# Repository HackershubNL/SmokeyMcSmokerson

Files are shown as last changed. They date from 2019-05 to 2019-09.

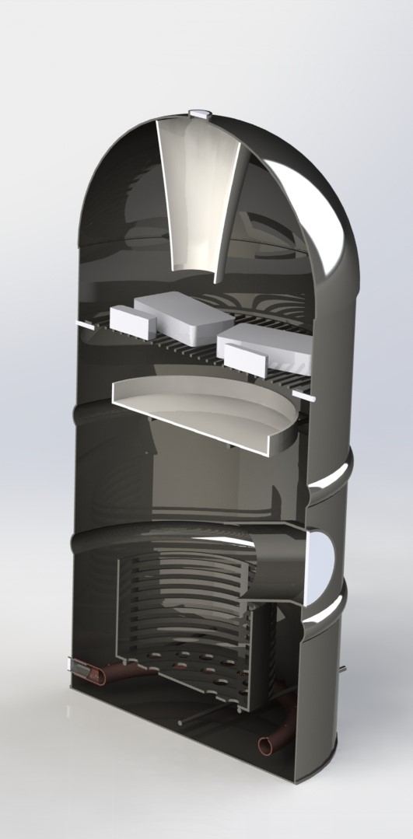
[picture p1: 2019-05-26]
Images/Full Assembly Rendering.JPG

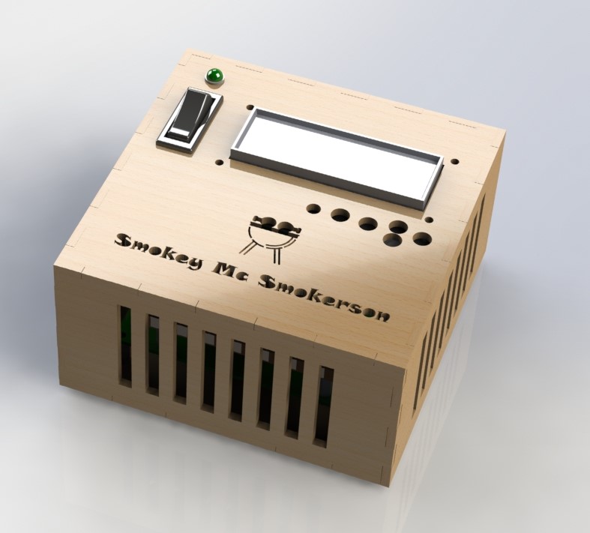
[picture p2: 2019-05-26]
Images/Controller Rendering.JPG

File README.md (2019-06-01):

# SmokeyMcSmokerson

## Introduction

This was inspired by the following projects:  
https://github.com/willblev/SmokeyTheBarrel  
https://github.com/jerrychangusa/ES96-Smart-Smoker  

Other sites and pages that were used in the process of making this project:  
https://amazingribs.com/  
https://genuineideas.com/ArticlesIndex/thecrutch.html

## Getting Started

The controller can be used separate from this smoker, meaning that you can use it on your own project. You will only need to place 4 of the 5 thermocouples in your smoker around the grill and have the fan blow into the bottom.

### Building the thing

It is currently in the last stages of design, as soon as the building starts, the build log will be published on: https://hackaday.io/project/165762-smokey-mc-smokerson  

### Running the thing

See Software/Controller for more info.

## Structure

```
-- Hardware  
  |-- Electronics - Design for the controller hardware  
  |-- Smoker - Design for the smoker itself  

-- Software  
  |-- Controller - Controller software

-- Images - Bunch of images
```

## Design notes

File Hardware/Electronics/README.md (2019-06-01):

# Smokey Mc Smokerson - Controller Hardware

## Intro

This is revision number one, already some improvement points have been identified such as using standard fan connectors instead of screw terminals and additional smoothing capacitors need to be included.  
1/6/2019 - Latest .sch and .brd files have 4 pin fan headers instead of the screw terminals.

## Design Decisions

The SN74AHCT125N Buffer is added to level shift the PWM signal from 3.3v to 5v. This has been done for better compatibility with different fans. Certain ones seem to accept 3.3v PWM signal but most 12V fans seem to require a 5v signal.

Plans for the controller housing can be found in Hardware/Smoker.

Additional GPIO pins are available through the 6 pin header for future usage.

The fan which will be used is the Sanyo Denki 9GA0412P6G001*, this is chosen due to the high static pressure because it will need to blow through a hose and the airflow spreader.  
*https://nl.farnell.com/sanyo-denki/9ga0412p6g001/axial-fan-40mm-12vdc-14-8cfm-47dba/dp/2768815 

## Bill of Materials  

Farnell shopping cart csv is included but the following items are not on the list:  
- Raspberry Pi + SD card (Assuming you have one)
- Thermocouple boards and probes, see link to Aliexpress below
- Fans

And some items have a minimum order quantity so you will get more than required.

### Main board

- 5x 5-pin female headers
- 2x 3-pin screw terminals - In latest .sch and .brd files these are switched for 4 pin headers so you can use a PC fan without having to cut the wire. The fan I chose comes with leaded connectors.
- 1x 6-pin male header
- 1x 4-pin male header
- 1x 2-pin male header
- 1x 2-pin Molex Mini Fit Jr Header
- 1x 5.5mm Barrel Jack 
- 1x 14-pin DIP socket
- 1x 40-pin female GPIO header  
- 1x RECOM R-78B5.0-2.0 5V 2A DC/DC Converter - You can use alternatives to this such as the V7805-2000 or any other TO220 Switching Regulators. Opted for the 2A version due to minimal price difference and it's nice to have an overhead.
- 1x 10uF capacitor  
- 1x 22uF capacitor  
- 1x 220 ohm resistor  
- 1x SN74AHCT125N

### Raspberry Pi

- 1x Raspberry Pi Zero W  
- 1x 40-pin male GPIO header

### Control Panel

- 1x Adafruit LCD display with I2C board
- 1x Panel mount led indicator
- 1x Rocker Switch 
- 1x 2 pin Molex Mini Fit Jr Receptacle  
- 2x Molex Crimp Contacts  
- 2x female jumper wire soldered to led indicator  
- 4x female - female jumper wires for display to main board
- 8x 11mm M2.5 standoffs
- 8x M2.5 - 6mm screws
- 8x M2.5 nuts

### Sensors

- 5x MAX6675 Thermocouple boards with probe - https://nl.aliexpress.com/item/MAX6675-Module-K-Type-Thermocouple-Thermocouple-Senso-Temperature-Degrees-Module-for-arduino/32841448771.html

### Other

- 1 or 2 12V PWM fans (according to barbecue forums a single 10CFM fan should be sufficient)

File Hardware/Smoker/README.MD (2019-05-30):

# Smokey Mc Smokerson - Smoker Design

## Introduction

After going through many options such as using flower pots, the decision was made to base it on an oil drum.  
The drum does not have as good flow and heat retention charactertics as flower pots or custom making a ceramic thing but it is fairly cheap and large.  
Most components have been modeled after off the shelf items available from hardware, garden and house supply stores.  
The only custom made items are the controller housing and fan mount (laser cut wood) and fan nozzle (3D printed), these will be placed in the `Custom Design Files` folder.

## Structure

The main assembly is `Barrel Smoker Assembly.SLDASM` which consists of multiple single parts and sub assemblies.

## Bill of Materials

- Online?
  - 55 Gallon (200 liter) Oil Drum
- Hardware Store
  - 55 cm barbecue grill
  - Expanded metal sheet (to make the coal basket) - 1x 35cm circle and 1x 110cm x 20cm
  - Steel wire to weave the metal sheets into a basket
  - 5x M10 1m threaded rod
  - 4x M10 50mm bolts
  - Bunch of M10 nuts
  - Bunch of M10 washers
  - 8x M6 washers - To attach the thermocouples, depending on which ones you get you might need another size
  - 4x M6 nuts - To attach the thermocouples, depending on which ones you get you might need another size
- Dollar Store style place
  - Largest round oven dish - preferably around 40cm diameter

## Building the thing

Coming soon

## Notes

Creating the air diffuser can be an expensive item due to the pipe size, alternatively use a 1 1/4 inch skin fitting. This is a fitting meant for ship through hull fluid flow.

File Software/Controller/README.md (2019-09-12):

# Smokey Mc Smokerson - Controller Software

## Introduction

Currently work in progress, this is conceptual code right now as the hardware has not been delivered yet. Simulated mode is built-in to show the usage.

## Running the thing

For full info check the wiki.

### Setup

Install dependencies with:  
`sudo bash ./setup.sh`

In `config.json` set your API key and optionally your Blynk server address. If the server address is an empty string, it will use the public Blynk Servers.

### Usage

Run the hardware tests with:  
`python3 ./smokey_mc_smokerson/run_tests.py`  
This will test the thermocouples and fan(s).

When using the setup script, it will install the controller as a service which starts on boot.  
To start and stop the service you can use:  
```
sudo /etc/init.d/smokey_service start
and
sudo /etc/init.d/smokey_service stop
```

Alternatively you can run it separately:  
`python3 ./smokey_mc_smokerson/smokey_mc_smokerson.py`  

The startup temperature values are located in `globals.py`, these can be changed using the Blynk app later on.

If it is run on anything but a Raspberry Pi, it will go into a simulated mode.

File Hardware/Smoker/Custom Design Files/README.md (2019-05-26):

# Smokey Mc Smokerson - Smoker Design - Custom Design Files

Production ready designs for custom made items are here / will go here:

- Controller Housing
- Fan Mount
- Fan Nozzle
  - Fan Nozzle.STL

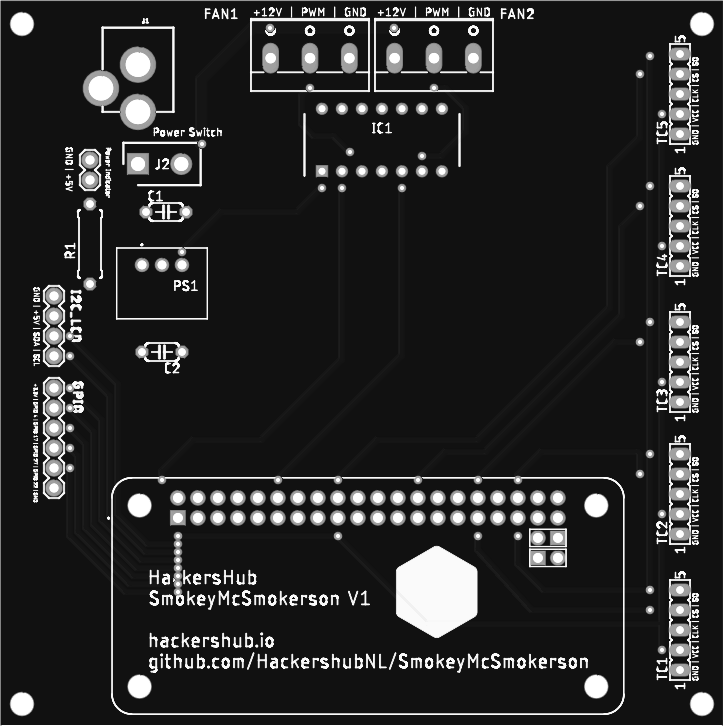
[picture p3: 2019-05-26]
Images/Controller Board Top View.png

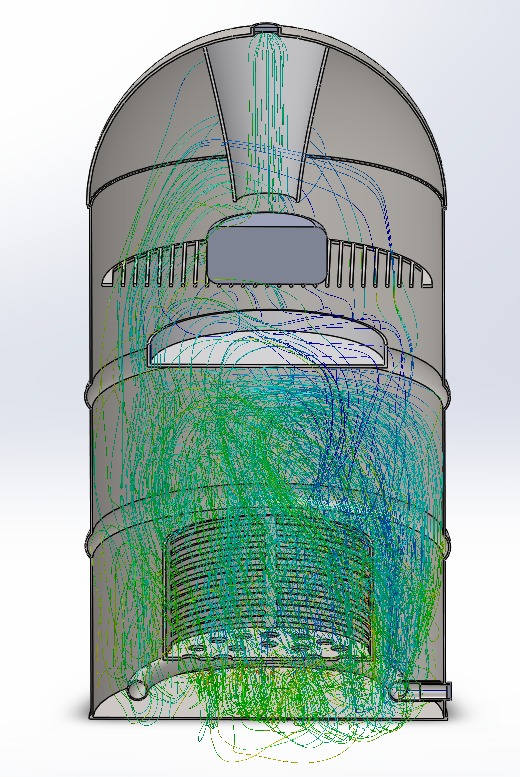
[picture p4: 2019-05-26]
Images/Air Flow Analysis.jpeg

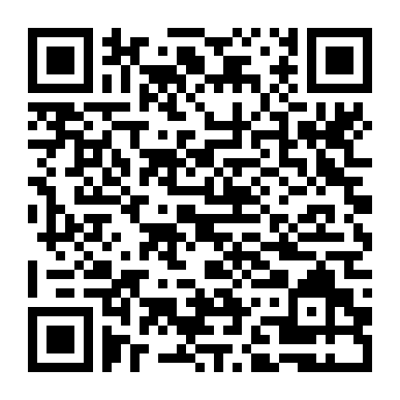
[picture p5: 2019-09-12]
Software/Controller/blynk_app.png

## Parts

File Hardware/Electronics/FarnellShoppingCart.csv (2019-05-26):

Artikelnr. | Ordercode | RoHS-compatibel? | Uw art.nr. | Opmerkingen | Hoeveelheid | Artikelnummer fabrikant | Naam fabrikant | Fabrikant / beschrijving | Beschikbaarheid | Prijs per stuk | Artikelprijs | Prijs na korting
1 | 1578490 | RoHS: YES / FTALATEN: TBA |  |  | 5.0 | MC34657 | MULTICOMP | MULTICOMP Wire-To-Board Connector, 4.2 mm, 2 Contacts, Header, 2266(5566)S Series, Through Hole, 2 Rows | 689 | 0.2650 | 1.33
2 | 1704304 | RoHS: YES / FTALATEN: TBA |  |  | 10.0 | 39-01-3022 | MOLEX | MOLEX Connector Housing, No Pull Tabs, UL 94V-2, Mini-Fit Jr. 5557 Series, Receptacle, 2 Ways, 4.2 mm | 17212 | 0.2120 | 2.12
3 | 1717002 | RoHS: YES / FTALATEN: TBA |  |  | 10.0 | CTB5202/3 | CAMDENBOSS | CAMDENBOSS Standard Terminal Block, Wire to Board, CTB5202 Series, 3 Contacts, 5 mm, Terminal Block, PCB | 11530 | 0.3640 | 3.64
4 | 1593461 | RoHS: YES / FTALATEN: TBA |  |  | 10.0 | 2212S-05SG-85 | MULTICOMP | MULTICOMP Board-To-Board Connector, 2.54 mm, 5 Contacts, Receptacle, 2212S Series, Through Hole, 1 Rows | Out of Stock | 0.1460 | 1.46
5 | 1854512 | RoHS: YES / FTALATEN: TBA |  |  | 1.0 | FC681465P | CLIFF ELECTRONIC COMPONENTS | CLIFF ELECTRONIC COMPONENTS DC Power Connector, Socket, 5 A, 2.5 mm, PCB Mount, Solder | 15554 | 1.7300 | 1.73
6 | 2668404 | RoHS: YES / FTALATEN: TBA |  |  | 10.0 | DILB14P-223TLF | AMPHENOL ICC (FCI) | AMPHENOL ICC (FCI) IC & Component Socket, 14 Contacts, DIP Socket, 2.54 mm, 7.62 mm, Copper Alloy | 3447 | 0.1480 | 1.48
7 | 2847248 | RoHS: YES / FTALATEN: TBA |  |  | 1.0 | 2214S-40SG-85 | MULTICOMP | MULTICOMP Board-To-Board Connector, 2.54 mm, 40 Contacts, Receptacle, Through Hole, 2 Rows | 5824 | 1.0100 | 1.01
8 | 2990790 | RoHS: YES / FTALATEN: TBA |  |  | 1.0 | RDEC71H106K3K1H03B | MURATA | MURATA Multilayer Ceramic Capacitor, 10 µF, 50 V, RDE Series, ± 10%, Radial Leaded, X7S | 901 | 1.5700 | 1.57
9 | 2990789 | RoHS: YES / FTALATEN: TBA |  |  | 1.0 | RDEC71E226K3K1H03B | MURATA | MURATA Multilayer Ceramic Capacitor, 22 µF, 25 V, RDE Series, ± 10%, Radial Leaded, X7S | 211 | 2.3100 | 2.31
10 | 1700228 | RoHS: YES / FTALATEN: TBA |  |  | 5.0 | MCRE000029 | MULTICOMP | MULTICOMP Through Hole Resistor, 220 ohm, MCRE Series, 125 mW, ± 5%, Axial Leaded, 200 V | 9048 | 0.0204 | 0.10
11 | 2725179 | RoHS: YES / FTALATEN: TBA |  |  | 5.0 | 2213S-40G | MULTICOMP | MULTICOMP Board-To-Board Connector, 2.54 mm, 40 Contacts, Header, Through Hole, 2 Rows | Out of Stock | 0.2600 | 1.30
12 | 2431245 | RoHS: YES / FTALATEN: TBA |  |  | 5.0 | 352-512-04 | MARL | MARL LED Panel Mount Indicator, Green, 2.1 VDC, 6.35 mm, 20 mA, 40 mcd, Not Rated | 43 | 0.2930 | 1.47
13 | 1756650 | RoHS: YES / FTALATEN: TBA |  |  | 10.0 | 39-00-0046 | MOLEX | MOLEX Contact, Mini-Fit Jr. 5556 Series, Socket, Crimp, 22 AWG, Tin Plated Contacts | 40400 | 0.0200 | 0.20
14 | 2762509 | RoHS: YES / FTALATEN: TBA |  |  | 1.0 | BC-32672 | BUD INDUSTRIES | BUD INDUSTRIES Jumper Wire, Bundle, 26 AWG, 10 Wires, Female - Female, 300 mm | 103 | 3.9900 | 3.99
15 | 2494583 | RoHS: YES / FTALATEN: TBA |  |  | 10.0 | 05.12.113 | ETTINGER | ETTINGER Standoff, Nickel Plated, Brass, M2.5, Hex Male-Female, 11 mm, 05.12 Series | 6511 | 0.3750 | 3.75
16 | 1419446 | RoHS: YES / FTALATEN: TBA |  |  | 1.0 | M2.5- HFST-Z100- | TR FASTENINGS | TR FASTENINGS Nut, Hex, M2.5, Steel, Bright Zinc Plated, Pack of 100 | 1493 | 1.3900 | 1.39
17 | 2494520 | RoHS: YES / FTALATEN: TBA |  |  | 10.0 | 01.51.221 | ETTINGER | ETTINGER Machine Screw, M2.5, 6 mm, Steel 8.8, Zinc, Pan Head Torx | 11965 | 0.0701 | 0.70
18 | 1749628 | RoHS: YES / FTALATEN: TBA |  |  | 5.0 | SN74AHCT125N . | TEXAS INSTRUMENTS | TEXAS INSTRUMENTS Buffer, 74AHCT125, 4.5 V to 5.5 V, DIP-14 | 151 Beschikbaar tot einde voorraad | 0.3200 | 1.60
19 | 678132 | RoHS: YES / FTALATEN: TBA |  |  | 5.0 | H8800VACL133 | ARCOLECTRIC | ARCOLECTRIC Rocker Switch, On-Off, SPST, Non Illuminated, Panel, Black, 8800 Series | 4479 | 0.6800 | 3.40
20 | 1097954 | RoHS: YES / FTALATEN: TBA |  |  | 1.0 | 77311-401-36LF | AMPHENOL ICC (FCI) | AMPHENOL ICC (FCI) Board-To-Board Connector, 2.54 mm, 36 Contacts, Header, BergStik 77311 Series, Through Hole, 1 Rows | 17275 | 0.9430 | 0.94
 |  |  |  |  |  |  | Subtotaal | 35.49
 |  |  |  |  |  |  | Totaal aantal goederen | 35.49
 |  |  |  |  |  |  | Levering | 0.00
 |  |  |  |  |  |  | BTW | 7.45
 |  |  |  |  |  |  | Totaal | 42.94

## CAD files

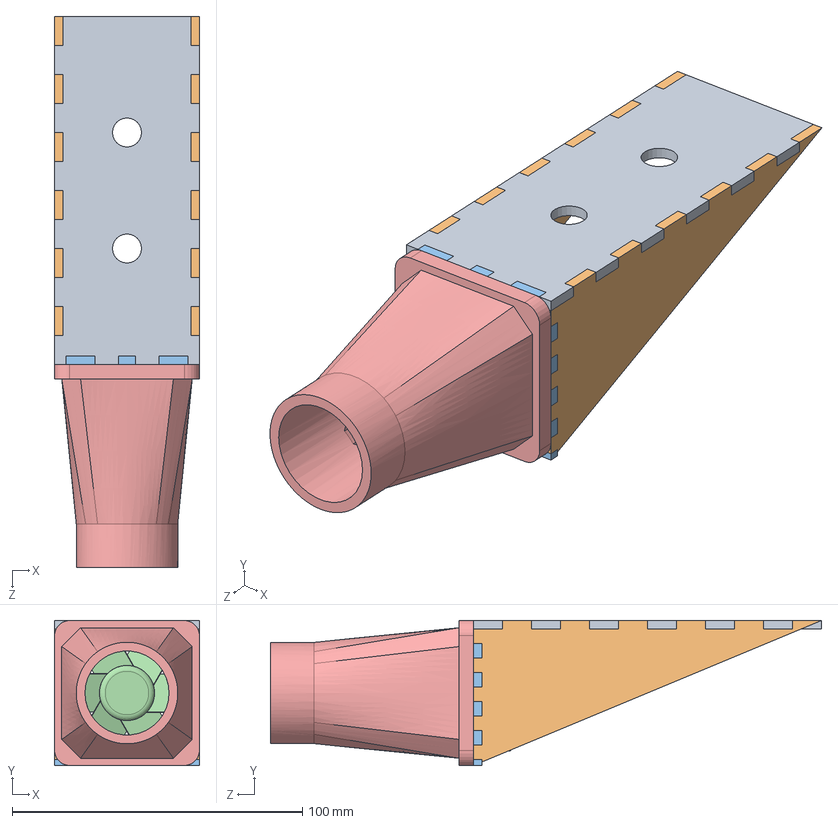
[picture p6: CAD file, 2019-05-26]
Hardware/Smoker/Fan Assembly.SLDASM
50.0 x 50.0 x 190.0 mm
Fan Mount Base
Fan Mount Side x 2
Fan Mount Front
40mm Fan
Fan Nozzle

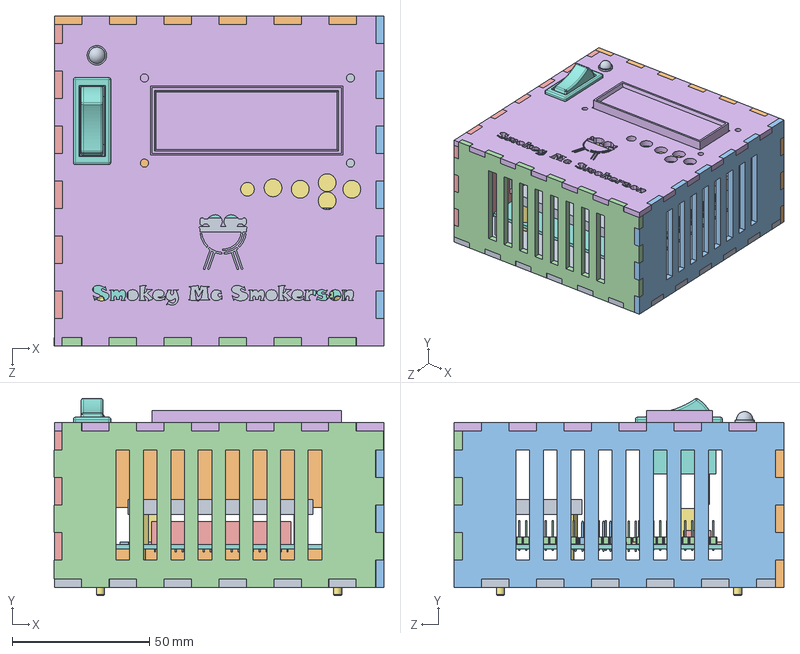
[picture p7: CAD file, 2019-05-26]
Hardware/Smoker/Controller Box.SLDASM
120.1 x 71.8 x 120.0 mm
Controller Box Base
Controller Box Side - Back
Controller Box Side - Right
Controller Box Side - Front
Controller Box Side - Left
Controller Box Top
Board Standoff x 8
controller v1
C050024X044_C050024X044 x 2
W237103_W237103 x 2
Header 2_54 Vertical 1x6
Header 2_54 Vertical 1x4
DIP794W53P254L1930H508Q14N_5.080000_SN74AHCT125N_5.080000
POWER_JACK_PTH_POWER_JACK
SHDR2W145P0X550_1X2_960X540X13_13.100000_0039281023_13.100000
1X02_J3_1X02
RASPBERRYPIZEROWV13_RASPBERRY_PI_ZERO_W__V1_3_
V78031500_V78051000
Header 2_54 Vertical 1x5 x 5
GPIO Header
LCD Screen
I2C Screen Module
Rocker Switch
Led

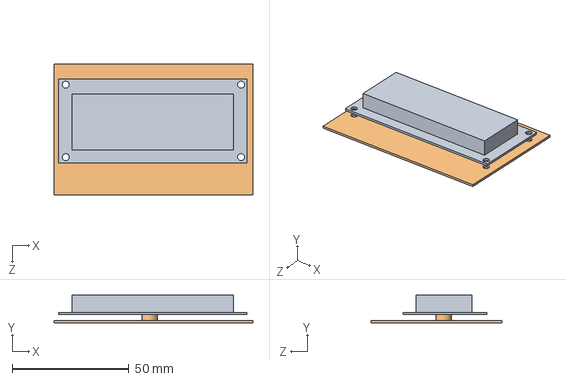
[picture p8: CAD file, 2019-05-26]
Hardware/Smoker/Display Module.SLDASM
85.1 x 11.9 x 56.1 mm
LCD Screen
I2C Screen Module

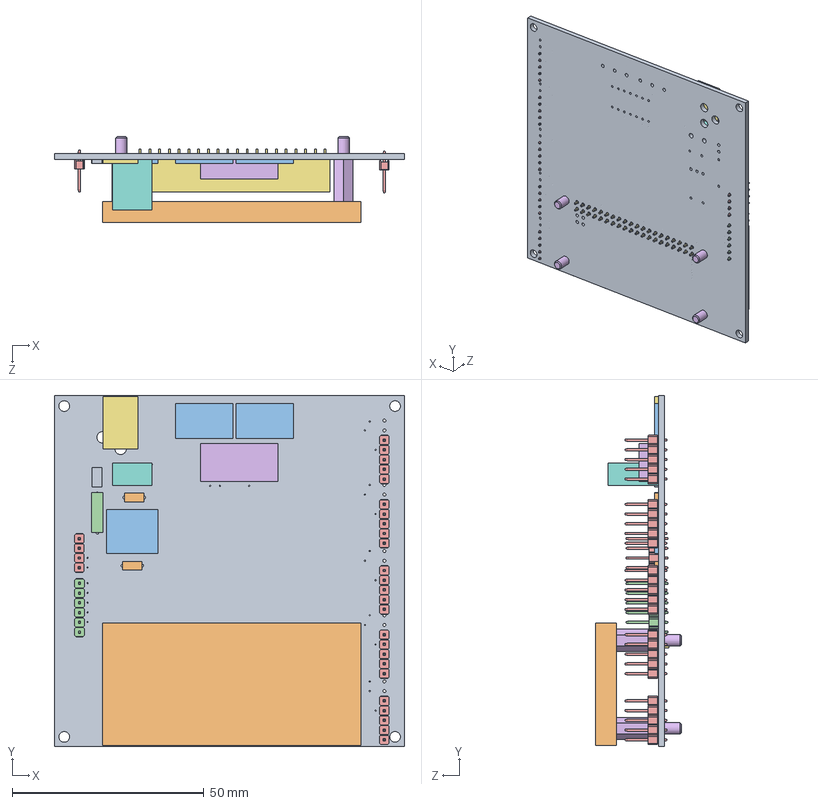
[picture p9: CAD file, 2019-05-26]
Hardware/Smoker/controller v1.SLDASM
91.4 x 91.7 x 22.4 mm
controller v1
C050024X044_C050024X044 x 2
W237103_W237103 x 2
Header 2_54 Vertical 1x6
Header 2_54 Vertical 1x4
DIP794W53P254L1930H508Q14N_5.080000_SN74AHCT125N_5.080000
POWER_JACK_PTH_POWER_JACK
SHDR2W145P0X550_1X2_960X540X13_13.100000_0039281023_13.100000
1X02_J3_1X02
RASPBERRYPIZEROWV13_RASPBERRY_PI_ZERO_W__V1_3_
V78031500_V78051000
Header 2_54 Vertical 1x5 x 5
Board Standoff x 4
GPIO Header

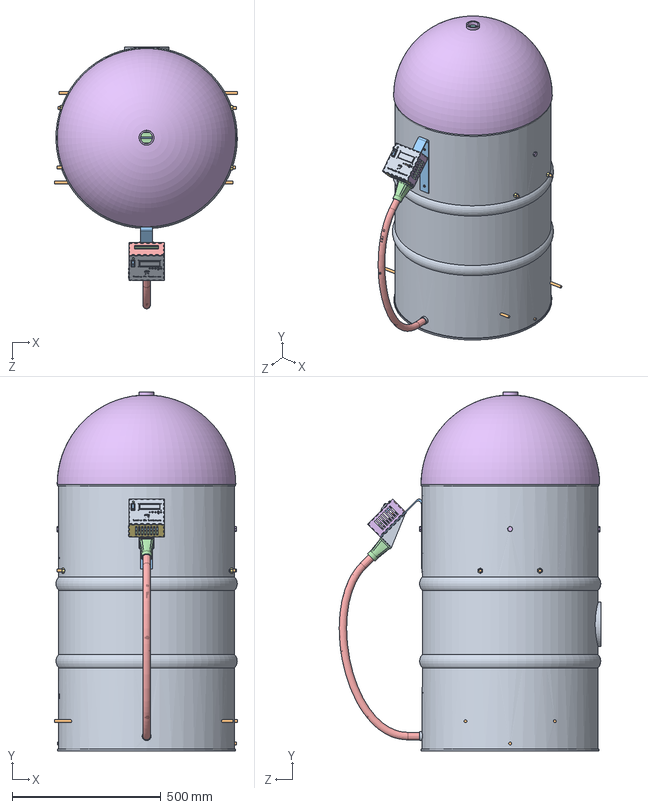
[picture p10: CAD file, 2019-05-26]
Hardware/Smoker/Barrel Smoker Assembly.SLDASM
615.3 x 1205.1 x 878.5 mm
Barrel
Coal Basket
Grill
Water Pan
Fake Rib x 5
Dome Lid
Inlet Spreader
Cone Baffle
Coal Shute
Threaded Rod x 5
Controller Bracket V2
Controller Box Base
Controller Box Side - Back
Controller Box Side - Right
Controller Box Side - Front
Controller Box Side - Left
Controller Box Top
Board Standoff x 8
controller v1
C050024X044_C050024X044 x 2
W237103_W237103 x 2
Header 2_54 Vertical 1x6
Header 2_54 Vertical 1x4
DIP794W53P254L1930H508Q14N_5.080000_SN74AHCT125N_5.080000
POWER_JACK_PTH_POWER_JACK
SHDR2W145P0X550_1X2_960X540X13_13.100000_0039281023_13.100000
1X02_J3_1X02
RASPBERRYPIZEROWV13_RASPBERRY_PI_ZERO_W__V1_3_
V78031500_V78051000
Header 2_54 Vertical 1x5 x 5
GPIO Header
LCD Screen
I2C Screen Module
Rocker Switch
Led
hex thin nut chamfered gradeab_iso x 2
hex bolt gradeab_iso x 4
hex nut gradec_iso x 4
Fan Mount Base
Fan Mount Side x 2
Fan Mount Front
40mm Fan
Fan Nozzle
Tube-1000X020^Tube_1-Barrel Smoker Assembly-003

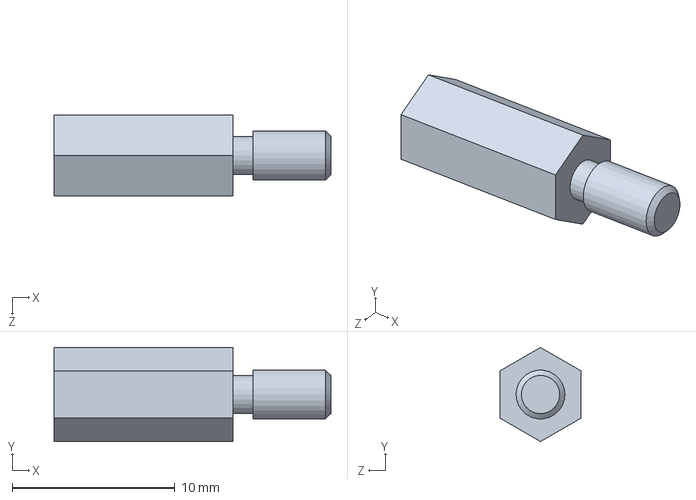
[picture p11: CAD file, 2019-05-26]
Hardware/Smoker/Board Standoff.SLDPRT
17.0 x 5.77 x 5.00 mm

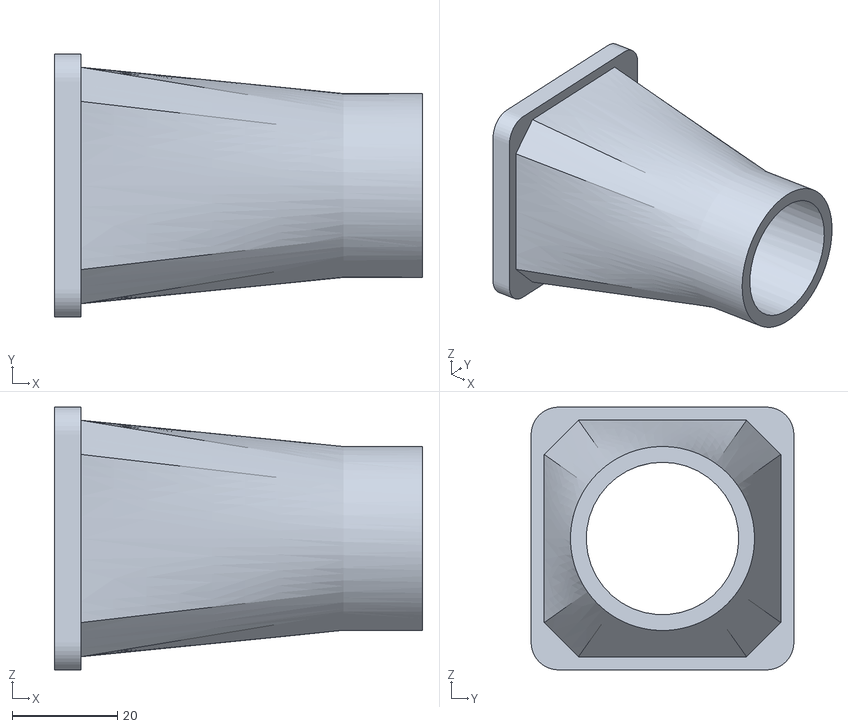
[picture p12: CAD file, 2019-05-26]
Hardware/Smoker/Custom Design Files/Fan Nozzle.STL
70.0 x 50.0 x 50.0

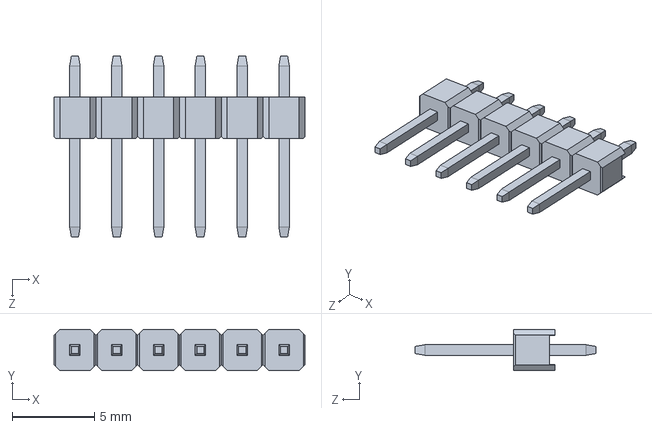
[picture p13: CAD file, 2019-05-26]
Hardware/Smoker/Header 2_54 Vertical 1x6.SLDPRT
15.2 x 2.50 x 11.0 mm

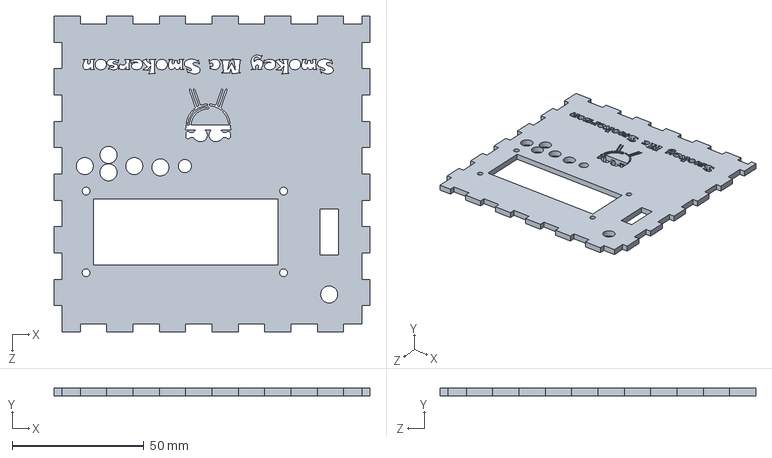
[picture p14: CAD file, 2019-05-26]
Hardware/Smoker/Controller Box Top.SLDPRT
120.0 x 3.00 x 120.0 mm

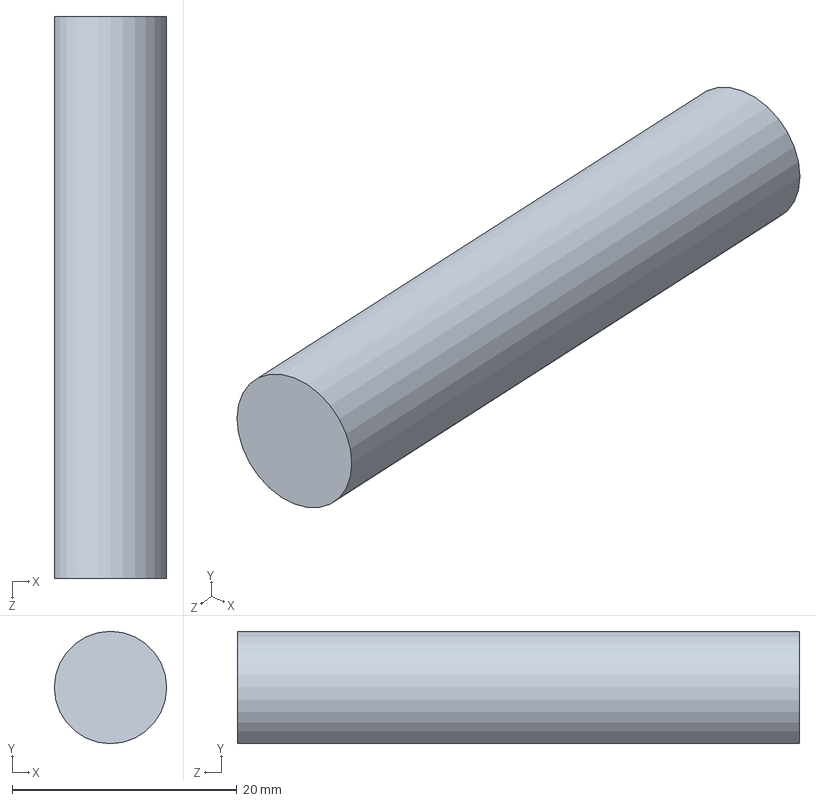
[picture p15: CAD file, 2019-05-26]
Hardware/Smoker/Grill Fix.SLDPRT
10.0 x 10.0 x 50.0 mm

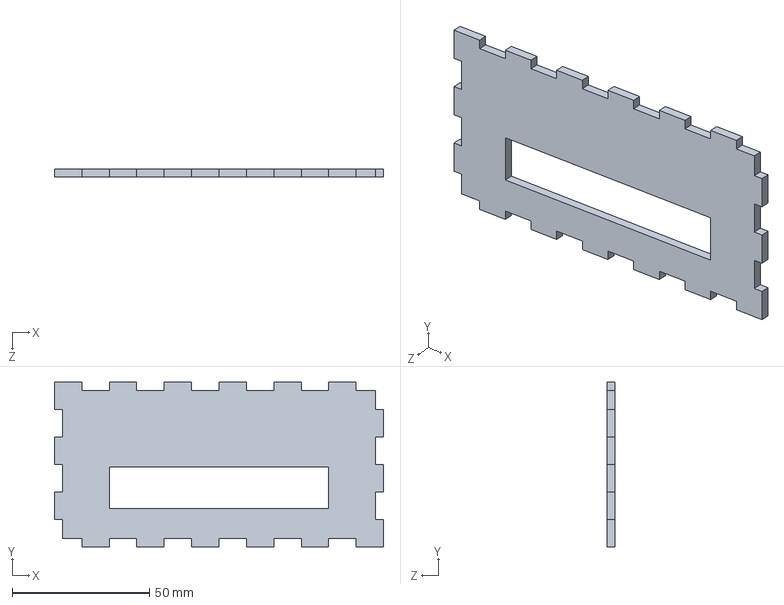
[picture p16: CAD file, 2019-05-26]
Hardware/Smoker/Controller Box Side - Back.SLDPRT
120.0 x 60.0 x 3.00 mm

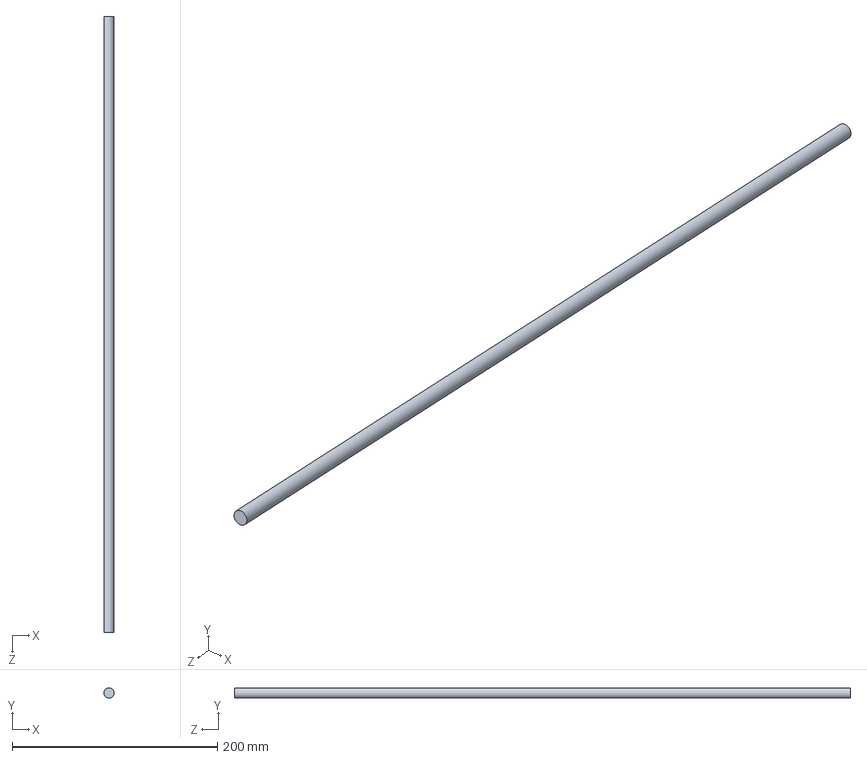
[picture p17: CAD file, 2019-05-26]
Hardware/Smoker/Threaded Rod.SLDPRT
10.0 x 10.0 x 600.0 mm

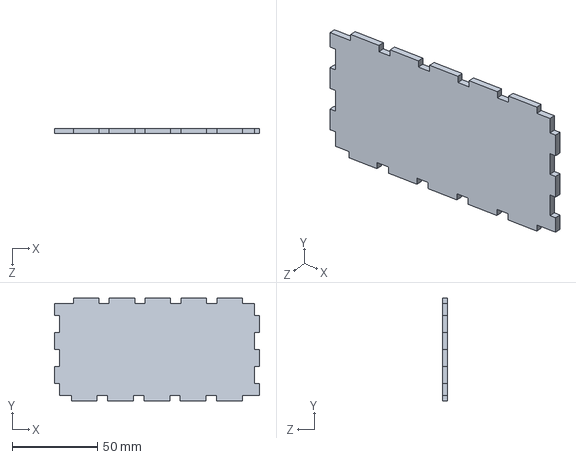
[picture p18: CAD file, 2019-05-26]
Hardware/Smoker/Controller Box Side.SLDPRT
120.0 x 60.0 x 3.00 mm

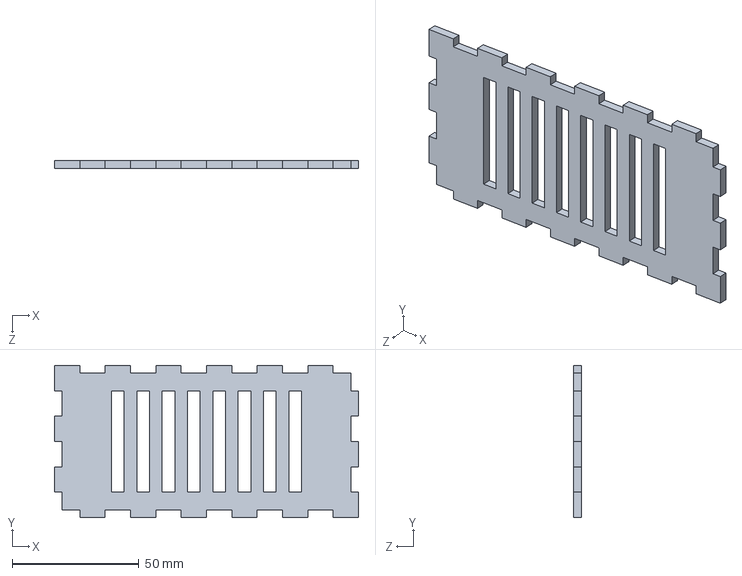
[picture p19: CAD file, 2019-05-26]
Hardware/Smoker/Controller Box Side - Right.SLDPRT
120.0 x 60.0 x 3.00 mm

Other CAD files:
Hardware/Smoker/Tube_1-Barrel Smoker Assembly.sldasm
Hardware/Smoker/Tube_1-Barrel Smoker Assembly-001.sldasm
Hardware/Smoker/Tube_1-Barrel Smoker Assembly-003.sldasm
Hardware/Smoker/Tube_1-Barrel Smoker Assembly-002.sldasm
Hardware/Smoker/40mm Fan.SLDPRT
Hardware/Smoker/Barrel.SLDPRT
Hardware/Smoker/Coal Basket.SLDPRT
Hardware/Smoker/Coal Shute.SLDPRT
Hardware/Smoker/Cone Baffle.SLDPRT
Hardware/Smoker/Controller Box Base.SLDPRT
Hardware/Smoker/Controller Box Side - Front.SLDPRT
Hardware/Smoker/Controller Box Side - Left.SLDPRT
Hardware/Smoker/Controller Bracket V2.SLDPRT
Hardware/Smoker/Controller Bracket.SLDPRT
Hardware/Smoker/Dome Lid.SLDPRT
Hardware/Smoker/Fan Mount Base.SLDPRT
Hardware/Smoker/Fan Mount Front.SLDPRT
Hardware/Smoker/Fan Mount Side.SLDPRT
Hardware/Smoker/Fan Nozzle.SLDPRT
Hardware/Smoker/GPIO Header.SLDPRT
Hardware/Smoker/Grill.SLDPRT
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

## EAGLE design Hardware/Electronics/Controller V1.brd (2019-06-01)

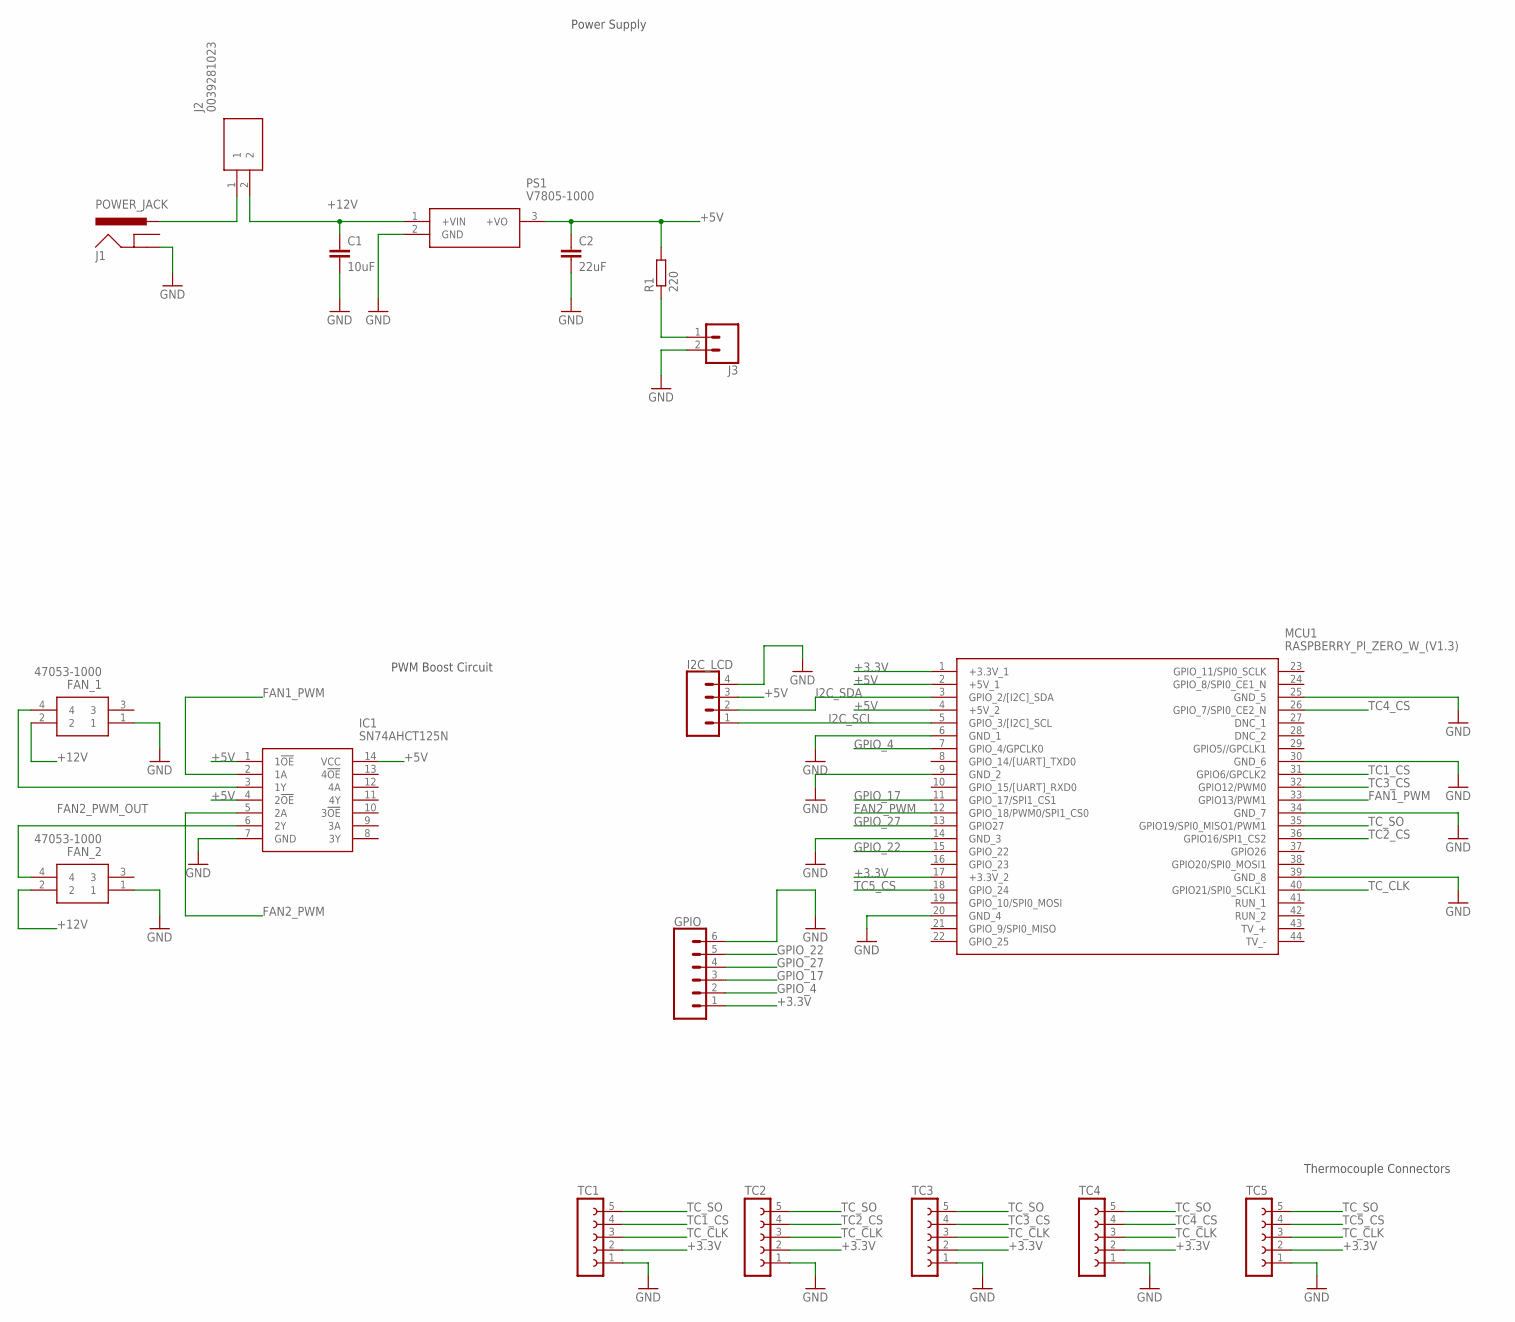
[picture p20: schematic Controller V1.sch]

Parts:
C1: 10uF; C050-024X044
C2: 22uF; C050-024X044
FAN_1, FAN_2: 47053-1000
GPIO: CONN_06SILK_FEMALE_PTH; 1X06
I2C_LCD: CONN_04PTH; 1X04
IC1: SN74AHCT125N; DIP794W53P254L1930H508Q14N
J1: POWER_JACK; POWER_JACK_PTH
J2: 0039281023; SHDR2W145P0X550_1X2_960X540X13
J3: CONN_02; 1X02
MCU1: RASPBERRY_PI_ZERO_W_(V1.3); RASPBERRYPIZEROWV13
PS1: V7805-1000; V78031500
R1: 220; 0309/10
TC1, TC2, TC3, TC4, TC5: FE05-1

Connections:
+3.3V: GPIO.1, MCU1.1 (+3.3V_1), MCU1.17 (+3.3V_2), TC1.2, TC2.2, TC3.2, TC4.2, TC5.2
+5V: C2.1, I2C_LCD.3, IC1.1 (1!OE), IC1.4 (2!OE), IC1.14 (VCC), MCU1.2 (+5V_1), MCU1.4 (+5V_2), PS1.3 (+VO), R1.2
+12V: C1.1, FAN_1.2, FAN_2.2, J2.2, PS1.1 (+VIN)
FAN1_PWM: IC1.2 (1A), MCU1.33 (GPIO13/PWM1)
FAN2_PWM: IC1.5 (2A), MCU1.12 (GPIO_18/PWM0/SPI1_CS0)
FAN2_PWM_OUT: FAN_2.4, IC1.6 (2Y)
FAN!_PWM_OUT: FAN_1.4, IC1.3 (1Y)
GND: C1.2, C2.2, FAN_1.1, FAN_2.1, GPIO.6, I2C_LCD.4, IC1.7 (GND), J1.GND, J3.2, MCU1.6 (GND_1), MCU1.9 (GND_2), MCU1.14 (GND_3), MCU1.20 (GND_4), MCU1.25 (GND_5), MCU1.30 (GND_6), MCU1.34 (GND_7), MCU1.39 (GND_8), PS1.2 (GND), TC1.1, TC2.1, TC3.1, TC4.1, TC5.1
GPIO_4: GPIO.2, MCU1.7 (GPIO_4/GPCLK0)
GPIO_17: GPIO.3, MCU1.11 (GPIO_17/SPI1_CS1)
GPIO_22: GPIO.5, MCU1.15 (GPIO_22)
GPIO_27: GPIO.4, MCU1.13 (GPIO27)
I2C_SCL: I2C_LCD.1, MCU1.5 (GPIO_3/[I2C]_SCL)
I2C_SDA: I2C_LCD.2, MCU1.3 (GPIO_2/[I2C]_SDA)
unnamed: J3.1, R1.1
TC1_CS: MCU1.31 (GPIO6/GPCLK2), TC1.4
TC2_CS: MCU1.36 (GPIO16/SPI1_CS2), TC2.4
TC3_CS: MCU1.32 (GPIO12/PWM0), TC3.4
TC4_CS: MCU1.26 (GPIO_7/SPI0_CE2_N), TC4.4
TC5_CS: MCU1.18 (GPIO_24), TC5.4
TC_CLK: MCU1.40 (GPIO21/SPI0_SCLK1), TC1.3, TC2.3, TC3.3, TC4.3, TC5.3
TC_SO: MCU1.35 (GPIO19/SPI0_MISO1/PWM1), TC1.5, TC2.5, TC3.5, TC4.5, TC5.5
VIN: J1.PWR, J2.1

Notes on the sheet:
Power Supply
PWM Boost Circuit
Thermocouple Connectors

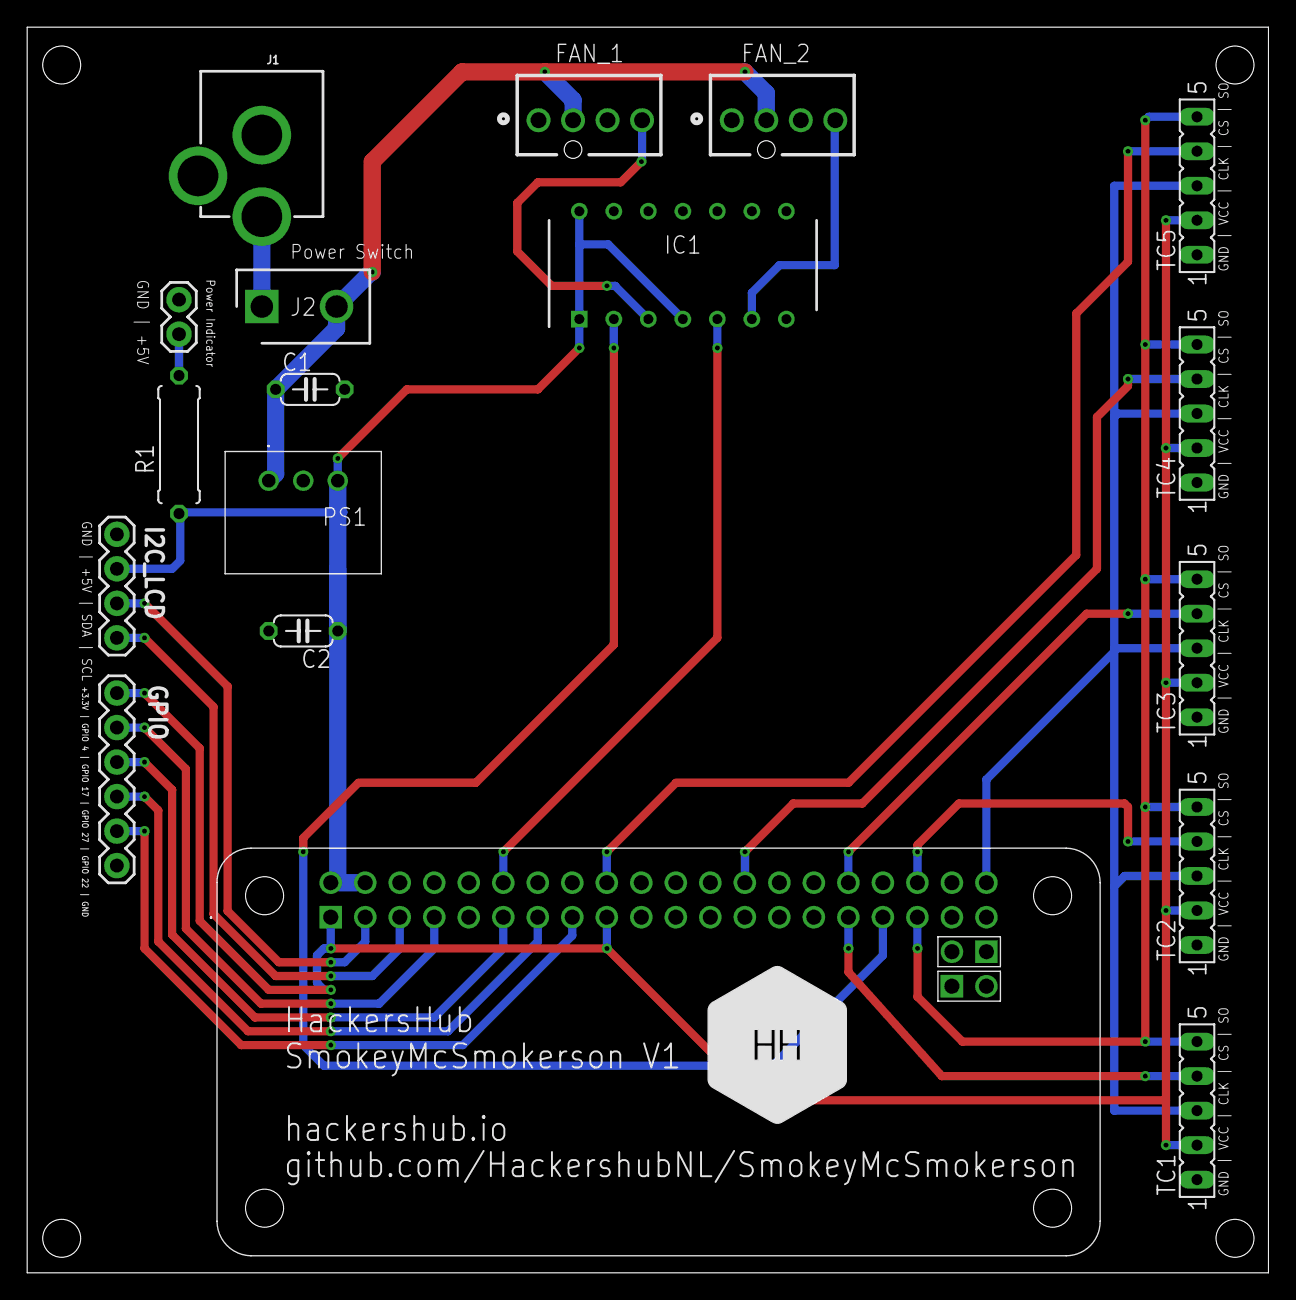
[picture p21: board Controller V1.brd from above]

Board: 2 copper layers, 91.4 x 91.7 mm, 18 parts (0 on the bottom side), 23 nets.

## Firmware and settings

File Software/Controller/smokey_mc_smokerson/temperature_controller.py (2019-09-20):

import time
from simple_pid import PID
import globals
import MAX6675
import Adafruit_GPIO
import Adafruit_GPIO.PWM as PWM
import Adafruit_GPIO.GPIO as GPIO

try:
    platform = Adafruit_GPIO.Platform.platform_detect()
    assert(platform == 1)
    gpio_platform = GPIO.get_platform_gpio()
    simulated_mode = False
except:
    simulated_mode = True
    globals.log('warning', "Temperature Controller - Platform is not a Raspberry Pi, running in simulated mode")

config = globals.config

#pins
CLK_pin = config['pin_outs']['thermocouple_clk']
DO_pin = config['pin_outs']['thermocouple_do']
TC1_CS_pin = config['pin_outs']['thermocouple_1_cs']
TC2_CS_pin = config['pin_outs']['thermocouple_2_cs']
TC3_CS_pin = config['pin_outs']['thermocouple_3_cs']
TC4_CS_pin = config['pin_outs']['thermocouple_4_cs']
TC5_CS_pin = config['pin_outs']['thermocouple_5_cs']
lid_switch_pin = config['pin_outs']['lid_switch']

#Fan variables
fan1_frequency = 25000
fan1_pin = config['pin_outs']['fan_1']
fan2_frequency = 25000
fan2_pin = config['pin_outs']['fan_2']

#Agressive Pid Tuning
aggressive_kp = config['pid_tunings']['aggressive']['kp']
aggressive_ki = config['pid_tunings']['aggressive']['ki']
aggressive_kd = config['pid_tunings']['aggressive']['kd']

#Conservative Pid Tuning
conservative_kp = config['pid_tunings']['conservative']['kp']
conservative_ki = config['pid_tunings']['conservative']['ki']
conservative_kd = config['pid_tunings']['conservative']['kd']

def calibrate_temperature_offset(TC1, TC2, TC3, TC4, TC5, pwm):
    
    globals.log('debug', 'Temperature Calibration - Running fan at 10% for a minute')

    #Run the fan at 10% for a minute
    set_fan_speed(pwm, 10)
    time.sleep(60)

    globals.log('debug', 'Temperature Calibration - Soaking for 2 minutes')
    #Kill the fan and soak for 2 minutes
    set_fan_speed(pwm, 0)
    time.sleep(120)

    #Measure temps
    TC1_temp = TC1.readTempC()
    time.sleep(0.1)
    TC2_temp = TC2.readTempC()
    time.sleep(0.1)
    TC3_temp = TC3.readTempC()
    time.sleep(0.1)
    TC4_temp = TC4.readTempC()
    time.sleep(0.1)
    TC5_temp = TC5.readTempC()

    #Average out the outside sensors and calculate the difference
    outside_temp_average = ((TC1_temp + TC2_temp + TC3_temp + TC4_temp) / 4)
    temperature_offset = TC5_temp - outside_temp_average

    globals.log('info', 'Temperature Calibration - Average edge temperature: {}, Inside temperature: {}, Temperature offset set at: {}'.format(outside_temp_average, TC5_temp, temperature_offset))

    globals.calibrate_temperature = False

    return temperature_offset

def set_fan_speed(pwm, fan_speed):
    if (simulated_mode == False):
        pwm.set_duty_cycle(fan1_pin, fan_speed)
        if (fan2_pin):
            pwm.set_duty_cycle(fan2_pin, fan_speed)

    globals.fan_speed = fan_speed

def simulate_temperature(simulated_temp):
    if (globals.fan_speed > 80):
        simulated_temp += 0.8

    if (globals.fan_speed > 60 and globals.fan_speed < 80):
        simulated_temp += 0.4

    if (globals.fan_speed > 30 and globals.fan_speed < 60):
        simulated_temp += 0.2

    if (globals.fan_speed < 30 and globals.fan_speed > 20):
        simulated_temp += 0.1

    if (globals.fan_speed < 20 and globals.fan_speed > 10):
        simulated_temp -= 0.1

    if (globals.fan_speed < 10):
        simulated_temp -= 0.2

    return simulated_temp

def set_pid_profile(pid, profile):

    if (globals.pid_profile_override == True):
        if (globals.current_pid_profile != "Manual Override"):
            globals.log('debug', 'Temperature Controller - Switched to PID Profile Manual Override')

        pid.Kp = globals.manual_pid_kp
        pid.Ki = globals.manual_pid_ki
        pid.Kd = globals.manual_pid_kd
            
        globals.current_pid_kp = globals.manual_pid_kp
        globals.current_pid_ki = globals.manual_pid_ki
        globals.current_pid_kd = globals.manual_pid_kd
        globals.current_pid_profile = "Manual Override"

    else:
        if (profile == 'aggressive'):
            if (globals.current_pid_profile != "Aggressive"):
                globals.log('debug', 'Temperature Controller - Switched to Aggressive PID profile')

            pid.Kp = aggressive_kp
            pid.Ki = aggressive_ki
            pid.Kd = aggressive_kd

            globals.current_pid_kp = aggressive_kp
            globals.current_pid_ki = aggressive_ki
            globals.current_pid_kd = aggressive_kd

            globals.current_pid_profile = "Aggressive"

        elif (profile == 'conservative'):
            if (globals.current_pid_profile != "Conservative"):
                globals.log('debug', 'Temperature Controller - Switched to Conservative PID profile')

            pid.Kp = conservative_kp
            pid.Ki = conservative_ki
            pid.Kd = conservative_kd

            globals.current_pid_kp = conservative_kp
            globals.current_pid_ki = conservative_ki
            globals.current_pid_kd = conservative_kd
            globals.current_pid_profile = "Conservative"

def run_temperature_controller():
    
    globals.log('info', 'Temperature Controller Started')

    #Initialize Pid
    pid = PID(Kp=aggressive_kp, Ki=aggressive_ki, Kd=aggressive_kd, setpoint=globals.target_barrel_temp, output_limits=(0, 100), auto_mode=True, proportional_on_measurement=True) # See documentation on proportial on measurement flag

    #Initialize temperature offset
    temperature_offset = 0

    if (simulated_mode == False):
        #Initialize Fan
        pwm = PWM.get_platform_pwm()
        pwm.start(fan1_pin, globals.fan_speed, fan1_frequency)

        #if a second fan is defined, initialize that as well
        if(fan2_pin):
            pwm.start(fan2_pin, globals.fan_speed, fan2_frequency)

        #if lid switch pin is defined, set it up as input
        if(lid_switch_pin):
            gpio_platform.setup(lid_switch_pin, GPIO.IN)

        #initialize thermocouples
        TC1 = MAX6675.MAX6675(CLK_pin, TC1_CS_pin, DO_pin)
        TC2 = MAX6675.MAX6675(CLK_pin, TC2_CS_pin, DO_pin)
        TC3 = MAX6675.MAX6675(CLK_pin, TC3_CS_pin, DO_pin)
        TC4 = MAX6675.MAX6675(CLK_pin, TC4_CS_pin, DO_pin)
        TC5 = MAX6675.MAX6675(CLK_pin, TC5_CS_pin, DO_pin)

        #Initialize Temperatures
        #read sensors
        TC1_temp = TC1.readTempC()
        time.sleep(0.1)
        TC2_temp = TC2.readTempC()
        time.sleep(0.1)
        TC3_temp = TC3.readTempC()
        time.sleep(0.1)
        TC4_temp = TC4.readTempC()
        time.sleep(0.1)
        TC5_temp = TC5.readTempC()

    else:
        #if in simulated mode, set to 20 degrees baseline
        TC1_temp = 20
        TC2_temp = 20
        TC3_temp = 20
        TC4_temp = 20
        TC5_temp = 20

        #and create empty pwm object
        pwm = None

    #set variables used in the loop
    TC5_temp_last = TC5_temp
    temp_weighted_avg_last = ((TC1_temp + TC2_temp + TC3_temp + TC4_temp) / 4)

    #keep looping until instructed otherwise
    while(globals.stop_threads == False):

        #update setpoint if it differs
        if (pid.setpoint != globals.target_barrel_temp):
            globals.log('debug', 'Temperature Controller - PID Setpoint changed to: {}'.format(globals.target_barrel_temp))
            pid.setpoint = globals.target_barrel_temp

        #read sensors and if in simulated mode, calculate based on fan speed
        if (simulated_mode == False):
            TC1_temp = TC1.readTempC()
            time.sleep(0.1)
            TC2_temp = TC2.readTempC()
            time.sleep(0.1)
            TC3_temp = TC3.readTempC()
            time.sleep(0.1)
            TC4_temp = TC4.readTempC()
            time.sleep(0.1)
            TC5_temp = TC5.readTempC()
        else:
            simulated_temp = simulate_temperature(TC1_temp)
            TC1_temp = TC2_temp = TC3_temp = TC4_temp = simulated_temp
            TC5_temp += 0.01

        #Calculations
        temp_weighted_avg = ((TC1_temp + TC2_temp + TC3_temp + TC4_temp) / 4) + globals.temperature_offset # + 45 From SmokeyTheBarrel: temperature compensation between outside and center of the barrel
        temp_weighted_avg_last = (2 * temp_weighted_avg_last + temp_weighted_avg) / 3
        globals.current_barrel_temp = temp_weighted_avg_last
        temperature_gap = globals.target_barrel_temp - temp_weighted_avg_last
        globals.current_temp_gap = temperature_gap

        TC5_temp_last=(2 * TC5_temp_last + TC5_temp)/3;
        globals.current_meat_temp = TC5_temp_last

        #use conservative pid profile for small temperature differences
        if (temperature_gap >= -10  and temperature_gap <= 10):
            set_pid_profile(pid, 'conservative')

        #otherwise use the aggresive profile
        else:
            set_pid_profile(pid, 'aggressive')

        #if lid switch pin is defined, check its state. If the lid is open, kill the fan. If the pin is not defined calculate and set the speed as required
        if (lid_switch_pin):
            lid_state = gpio_platform.input(lid_switch_pin)

            if (lid_state == GPIO.HIGH):
                set_fan_speed(pwm, 0)
                globals.lid_open = True
            else:
                #calculate new fan speed and set the fan speed
                #only do the pid calculation when the lid is closed to prevent confusing the pid
                pid_output = pid(temp_weighted_avg_last)
                set_fan_speed(pwm, pid_output)
                globals.lid_open = False

        else:
            #calculate new fan speed and set the fan speed
            pid_output = pid(temp_weighted_avg_last)
            set_fan_speed(pwm, pid_output)

        #if the calibrate option has been selected
        if (globals.calibrate_temperature == True):

            globals.log('info', 'Temperature Calibration Started, stopping PID controller')

            #stop the pid
            pid.auto_mode = False

            #run the calibrate function
            globals.temperature_offset = calibrate_temperature_offset(TC1, TC2, TC3, TC4, TC5, pwm)

            #reenable the pid
            pid.auto_mode = True
            globals.log('info', 'Temperature Calibration Finished, PID controller started')

        #sleep for a second
        time.sleep(1)

        ###### End of loop

    if (simulated_mode == False):
        pwm.stop(fan1_pin)
        if (fan2_pin):
            pwm.stop(fan2_pin)

    globals.log('info', 'Temperature Controller Stopped')

if __name__ == "__main__":
    globals.log('error', 'Start the temperature controller with ./smokey_mc_smokerson.py')

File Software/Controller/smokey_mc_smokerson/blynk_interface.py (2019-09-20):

import blynklib
import time
import blynktimer
from datetime import datetime
from datetime import timedelta  
import globals
import os

#Set Globals
config = globals.config
cooking_dict = globals.cooking_dict

#Connect to Blynk server
if (config['blynk']['server'] == ''):
    blynk = blynklib.Blynk(config['blynk']['auth'])
    
else:
    blynk = blynklib.Blynk(config['blynk']['auth'], server=config['blynk']['server'], port=config['blynk']['server_port'])

#Initialize Blynk Timer
timer = blynktimer.Timer()

#Set base strings
recipe_info_string = "Recipe: {}\n\nMeat Type: {}\n\nSmoker Temperature: {}C\n\nTarget Meat Temperature: {}C\n\nCooking Time: {}\n\nInfo:\n{}"

#Set base variable
cooking_start = None
cooking_end = None
selected_profile = 1
init_loop = True
manual_timer_hours = 0
manual_timer_minutes = 0
timer_notification_sent = False
meat_ready_notification_sent = False

#Set Blynk Vpins
current_barrel_temp_vpin = config['blynk']['vpins']['current_barrel_temp']['pin']
current_meat_temp_vpin = config['blynk']['vpins']['current_meat_temp']['pin']
target_barrel_temp_vpin = config['blynk']['vpins']['target_barrel_temp']['pin']
target_meat_temp_vpin = config['blynk']['vpins']['target_meat_temp']['pin']
recipe_selector_vpin = config['blynk']['vpins']['recipe_selector']['pin']
status_text_vpin = config['blynk']['vpins']['status_text']['pin']
fan_speed_vpin = config['blynk']['vpins']['fan_speed']['pin']
recipe_description_vpin = config['blynk']['vpins']['recipe_description']['pin']
cook_time_remaining_vpin = config['blynk']['vpins']['cook_time_remaining']['pin']
manual_timer_hours_vpin = config['blynk']['vpins']['manual_timer_hours']['pin']
manual_timer_minutes_vpin = config['blynk']['vpins']['manual_timer_minutes']['pin']
confirm_recipe_vpin = config['blynk']['vpins']['confirm_recipe']['pin']
set_manual_timer_vpin = config['blynk']['vpins']['set_manual_timer']['pin']
mode_selector_vpin = config['blynk']['vpins']['mode_selector']['pin']
current_pid_kp_vpin = config['blynk']['vpins']['current_pid_kp']['pin']
current_pid_ki_vpin = config['blynk']['vpins']['current_pid_ki']['pin']
current_pid_kd_vpin = config['blynk']['vpins']['current_pid_kd']['pin']
current_pid_profile_vpin = config['blynk']['vpins']['current_pid_profile']['pin']
current_temp_gap_vpin = config['blynk']['vpins']['current_temp_gap']['pin']
manual_pid_kp_vpin = config['blynk']['vpins']['manual_pid_kp']['pin']
manual_pid_ki_vpin = config['blynk']['vpins']['manual_pid_ki']['pin']
manual_pid_kd_vpin = config['blynk']['vpins']['manual_pid_kd']['pin']
pid_profile_override_vpin = config['blynk']['vpins']['pid_profile_override']['pin']
system_shutdown_vpin = config['blynk']['vpins']['system_shutdown']['pin']
calibrate_temperature_vpin = config['blynk']['vpins']['calibrate_temperature']['pin']
temperature_offset_vpin = config['blynk']['vpins']['temperature_offset']['pin']

def strfdelta(tdelta, fmt):
    d = {"days": tdelta.days}
    d["hours"], rem = divmod(tdelta.seconds, 3600)
    d["minutes"], d["seconds"] = divmod(rem, 60)
    d["hours"] = str(d["hours"]).rjust(2, '0')
    d["minutes"] = str(d["minutes"]).rjust(2, '0')
    d["seconds"] = str(d["seconds"]).rjust(2, '0')
    return fmt.format(**d)
          
@timer.register(interval=5, run_once=False)
def update_ui():
    global timer_notification_sent
    global meat_ready_notification_sent

    blynk.virtual_write(current_barrel_temp_vpin, int(globals.current_barrel_temp))
    blynk.virtual_write(current_meat_temp_vpin, int(globals.current_meat_temp))
    blynk.virtual_write(fan_speed_vpin, globals.fan_speed)
    blynk.virtual_write(current_pid_kp_vpin, globals.current_pid_kp)
    blynk.virtual_write(current_pid_ki_vpin, globals.current_pid_ki)
    blynk.virtual_write(current_pid_kd_vpin, globals.current_pid_kd)
    blynk.virtual_write(current_pid_profile_vpin, globals.current_pid_profile)
    blynk.virtual_write(current_temp_gap_vpin, int(globals.current_temp_gap))
    blynk.virtual_write(temperature_offset_vpin, globals.temperature_offset)

    if (cooking_end):
        time_delta = cooking_end - datetime.now()
        if (time_delta.days >= 0):
            message = strfdelta(time_delta, "{hours}:{minutes}:{seconds}")
        else:
            message = "Ready"
            if (timer_notification_sent == False):
                blynk.notify("Timer Expired")
                globals.log('debug', 'Blynk - Sent Timer Expired Push Notification')
                timer_notification_sent = True
        
        blynk.virtual_write(cook_time_remaining_vpin, message)


    if ((globals.target_meat_temp - globals.current_meat_temp) < 1 and meat_ready_notification_sent == False):
        blynk.notify("Food is Ready!")
        globals.log('debug', 'Blynk - Sent Food is Ready Push Notification')
        meat_ready_notification_sent = True

@blynk.handle_event('write V{}'.format(target_barrel_temp_vpin))
def write_target_barrel_temp_handler(pin, value):
    globals.log('debug', 'Blynk - Target Smoker Temperature Set to: {}'.format(value[0]))

    globals.target_barrel_temp = int(value[0])

@blynk.handle_event('write V{}'.format(target_meat_temp_vpin))
def write_target_meat_temp_handler(pin, value):
    global meat_ready_notification_sent
    globals.log('debug', 'Blynk - Target Meat Temperature Set to: {}'.format(value[0]))
    meat_ready_notification_sent = False
    globals.target_meat_temp = int(value[0])

@blynk.handle_event('write V{}'.format(recipe_selector_vpin))
def write_recipe_selector_handler(pin, value):
    global selected_profile
    index = value[0]
    selected_profile = index
    globals.log('debug', 'Blynk - Recipe Selector Changed to: {}'.format(value[0]))

    blynk.virtual_write(recipe_description_vpin, 'clr')
    blynk.virtual_write(recipe_description_vpin, recipe_info_string.format(cooking_dict[index]['name'], cooking_dict[index]['meat_type'], cooking_dict[index]['barrel_temp'], cooking_dict[index]['meat_temp'], time.strftime('%H:%M:%S', time.gmtime(cooking_dict[index]['cooking_time'])), cooking_dict[index]['description']))
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

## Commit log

2019-05-28 Revert "Update to basic working version"
    This reverts commit d02105a139e514b22ce7739d7c3cd99efc8185a7.
    [blynk_interface.py, globals.py, smokey_mc_smokerson.py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]
2019-05-28 Revert "Revert "Update to basic working version""
    This reverts commit 48b70cc33131ed02f2104fd57b75453119ada5e7.
    [blynk_interface.py, globals.py, smokey_mc_smokerson.py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]
2019-06-01 Changed screw terminals for actual 4 pin PWM fan headers
    [Controller V1.brd, Controller V1.sch]
2019-06-01 Small updates and bug fixes
    [blynk_interface.py, globals.py, run_tests.py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]
2019-09-12 Update of system services both for the Blynk server and the Smokey service. Added temperature offset option to the config file and temperature controller.
2019-09-18 Added temperature calibration function
2019-09-20 Changes to temperature offset calibration

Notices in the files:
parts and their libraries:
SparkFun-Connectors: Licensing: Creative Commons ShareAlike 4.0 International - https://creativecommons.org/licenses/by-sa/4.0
